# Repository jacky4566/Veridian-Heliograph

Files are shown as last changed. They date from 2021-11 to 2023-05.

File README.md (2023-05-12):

# Veridian-Heliograph
## What is it?
A hardy solar powered giver of GPS XYZ. Born from a need to always have a GPS device that can run for decades without any lithium batteries.
The Heliograph seeks to always provide a GPS Lat/Long position for the most severe travelers.
The whole device is cast in water clear epoxy, no ports, no holes, no batteries. Just a robust device that will provide a GPS position whenever outside.
A single M4 thread is provided for keychain or mounting on your favorite motorbike.

## Who wants it?
- Offshore Sailors
- Motorbikers
- Outdoorsmen
- Overlanders
- GNSS nerds

## Expected life
TBD

## Tech Features
- 2x 160mW solar panels
- TI nA Buck-Boost TPS63802
- 3.6V 70F Hybrid supercap
- UBlox Ultra low power M10 GPS processor
- STM32L432 MCU
- 3 Axis accelerometer with tap input, LIS3DH
- Sharp Sun readable Memory Display
- M4 screw thread for keychain or mounting

# Development and Details

## POWER SYSTEM
The power system comprises of 2 high efficiency solar panels at 120 degrees.  With this approach I hope the product design will always have access to some light to charge the super caps. Incoming power from the solar panels is feed through individual low drop shotcky diodes. With the diodes we loose ~200mV which is acceptable. 

The Supercaps are feed into Ti TPS63802 which provides buck-boost topography from the supercaps. Effectively allowing maximum use of the supercaps linear charge. 1.3 - 5.5V should be supported. Ti does also make an integrated BQ25570 MPPT with buck however I wanted to maximize the super caps voltage range.

VDD was selected at 3.0 volts as this was the minimum for the Sharp Memory LCD and the uBlox M10 GNSS chip. The M10 chip does also have a 1.8V version however we are still limited by the LCD. It might be possible to add a level converter however that quickly increases our BOM. The Buck-Boost seems like a good balance of low BOM and high efficiency.

## FIRMWARE
The firmware was written with the help of STM32CUBEIDE. The CubeIDE is pretty great for pre-generated code however some aspects can be hard to figure out for a novice. Since the BLE code could already be generated by the IDE most of my work was focused on the board level integration. Reading the sensors and putting that data into a nice GUI.
Firmware Features:
-	16MHz CPU speed coupled with 32.768kHz real time clock.
-	ADC 1Hz with DMA functionality to gather voltages. Supercap, temperature, and solar voltages.
-	SPI Display updating
-	GNSS processing using the Ublox PVT message. Less bytes to process compared to traditional NEMA messages. Super-e ultra low power tracking is set along side a software standby.
-	Accelerometer processing and Tap inputs

Some programming challenges I faced with my fight against CubeIDE:
-	Setting up the ADC DMA with proper callbacks. Some of the HAL calls need to be just right for the desired callbacks.
-	Learing about the SHARP display strange packet formatting. Data needs to be send as LSB.

## Housing
The Heliograph is essential without a housing. A basic model was 3D printed, then a reverse mold was made in rubber so the PCB and solar panels could be placed in a cavity and cast. Further development to come here.

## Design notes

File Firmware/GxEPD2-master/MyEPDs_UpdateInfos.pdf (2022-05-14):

List of my e-paper displays and their update times and behavior

size | | | panel | controller | full update | | | | comment
inches | depth | pixel | | | time sec | time sec | to buffer | to screen
1,54 | b/w | 200x200 | GDEP015OC1 | IL3829 | 1,2 | 0,3 | √ | √
1,54 | 3-color | 200x200 | GDEW0154Z04 | IL0376F | 7,2 | 7,2 | - | - | controller has no window part addressing
2,13 | b/w | 128x250 | GDE0213B1 | IL3895 | 3,9 | 0,3 | √ | √ | phased out
2,13 | b/w | 128x250 | GDEH0213B72 | IL3897 | 1,7 | 0,2 | √ | √ | new replacement
2,13 | b/w | 128x250 | GDEH0213B73 | SSD1675B | 3,8 | 0,2 | √ | √ | newer replacement
2,13 | 3-color | 104x212 | GDEW0213Z16 | IL0373 | 15 | 15 | √ | √ | screen boarder flashes also
2.13 | b/w | 104x212 | GDEW0213I5F | IL0373 | 2,1 | 0,3 | √ | √ | flexible display
2,6 | b/w | 152x296 | GDEW026T0 | IL0373 | 1,6 | 1,3 | √ | √
2,7 | b/w | 176x264 | GDEW027W3 | IL91874 | 2 | 0,4 | √ | √ | with wavetable from new demo source
2,7 | 3-color | 176x264 | GDEW027C44 | IL91874 | 16 | 16 | √ | √ | leaves visible boarder of partial window
2,9 | b/w | 128x296 | GDEH029A1 | IL3820 | 1,6 | 0,42 | √ | √
2,9 | b/w | 128x296 | GDEW029T5 | IL0373 | 2,1 | 0,4 | √ | √
2,9 | 3-color | 128x296 | GDEW029Z10 | IL0373 | 15 | 15 | √ | √ | screen boarder flashes also
3,7 | b/w | 240x416 | GDEW0371W7 | IL0324 | 3 | 1,5 | √ | √ | charge balancing waveform table for differential update
4,2 | b/w | 400x300 | GDEW042T2 | IL0398 | 1,6 | 0,6 | √ | √ | new waveform table for differential update
4,2 | 3-color | 400x300 | GDEW042Z15 | IL0398 | 16 | 16 | √ | - | refresh to partial screen would modify the other half screen
5,83 | b/w | 600x448 | GDEW0583T7 | IL0371 | 15 | 15 | √ | - | controller provides no differential update
7,5 | b/w | 640x384 | GDEW075T8 | IL0371 | 4,3 | 4,3 | √ | - | controller provides no differential update
7,5 | b/w | 800x480 | GDEW075T7 | GD7965 | 4,2 | 1,6 | √ | √ | charge balancing waveform table for differential update
7,5 | 3-color | 640x384 | GDEW075Z09 | IL0371 | 32 | 32 | √ | - | controller provides no differential update
7,5 | 3-color | 800x480 | GDEW075Z08 | GD7965 | 17 | 17 | √ | (√) | 3-color allows no differential update

times are "busy active" times after refresh command sent to controller
"-" partial update to screen: whole screen updates (and flashes)
(√) partial update can be disabled in GxEPD2 (usePartialUpdate = false) for better image

4.2" b/w: new waveform table for differential update, compromise between ghosting and persistence

resolution | partial update

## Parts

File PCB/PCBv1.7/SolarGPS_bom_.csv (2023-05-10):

Component | Description | Part | References | Value | Footprint | Quantity Per PCB | Datasheet | Manufacture | Category | DK_Datasheet_Link | DK_Detail_Page | Digi-Key_PN | Family | MPN | Manufacturer | Status
1 | Unpolarized capacitor, small symbol | C_Small | C13 C15 | 11pF | C_0603_1608Metric | 2 | ~
2 | Unpolarized capacitor, small symbol | C_Small | C1 C2 C3 C6 C7 C8 C12 C14 C16 C17 | 1uF | C_0603_1608Metric | 10 | ~
3 | Unpolarized capacitor, small symbol | C_Small | C9 C10 | 22uF | C_1206_3216Metric | 2 | ~
4 | Polarized capacitor | C_Polarized | C4 | 70F | TPLC3R8-25MR8X20 | 1 | ~
5 | Light emitting diode, small symbol | LED_Small | D1 | LED_Small | D_0805_2012Metric | 1 | ~
6 | Generic connector, single row, 01x04, script generated (kicad-library-utils/schlib/autogen/connector/) | Conn_01x04_Male | J8 | Conn_01x04_Male | PinSocket_1x04_P2.54mm_Vertical | 1 | ~
7 | Generic connector, single row, 01x10, script generated (kicad-library-utils/schlib/autogen/connector/) | Conn_01x10_Female | J1 | Conn_01x10_Female | LS013B7DH03 | 1 | ~
8 | Generic connector, double row, 02x03, odd/even pin numbering scheme (row 1 odd numbers, row 2 even numbers), script generated (kicad-library-utils/schlib/autogen/connector/) | Conn_02x03_Odd_Even | J6 | Conn_02x03_Odd_Even | Tag-Connect_TC2030-IDC-NL_2x03_P1.27mm_Vertical | 1 | ~
9 | Generic connector, single row, 01x01, script generated (kicad-library-utils/schlib/autogen/connector/) | Conn_01x01_Female | J2 J3 J4 J5 | GND | PinHeader_1x01_P2.54mm_Vertical | 4 | ~
10 | Generic screw terminal, single row, 01x01, script generated (kicad-library-utils/schlib/autogen/connector/) | Screw_Terminal_01x01 | J7 | Screw_Terminal_01x01 | M4_RA_7792 | 1 | ~ | Keystone Electronics
11 | USB 2.0-only Type-C Receptacle connector | USB_C_Receptacle_USB2.0 | J9 | USB_C_Receptacle_USB2.0 | USB_TYPE_C_PCB | 1 | https://www.usb.org/sites/default/files/documents/usb_type-c.zip
12 | Inductor, small symbol | L_Small | L1 | 0.47uH | L_0805_2012Metric_Pad1.15x1.40mm_HandSolder | 1 | ~
13 | Resistor, small symbol | R_Small | R10 | 10 | R_0805_2012Metric | 1 | ~
14 | Resistor, small symbol | R_Small | R8 R9 R11 R13 | 5.1K | R_0603_1608Metric | 4 | ~
15 | Resistor, small symbol | R_Small | R1 R4 R7 R12 | 86.6k | R_0603_1608Metric | 4 | ~
16 | Resistor, small symbol | R_Small | R2 R3 R6 | 432k | R_0603_1608Metric | 3 | ~
17 | IMU ACCEL/GYRO I2C/SPI 14LGA | BMI160 | U4 | BMI160 | BMI160 | 1 | https://ae-bst.resource.bosch.com/media/_tech/media/datasheets/BST-BMI160-DS000.pdf |  | Sensors, Transducers | https://ae-bst.resource.bosch.com/media/_tech/media/datasheets/BST-BMI160-DS000.pdf | /product-detail/en/bosch-sensortec/BMI160/828-1057-1-ND/6136308 | 828-1057-1-ND | Motion Sensors - IMUs (Inertial Measurement Units) | BMI160 | Bosch Sensortec | Active
18 | Ideal Diode, Ultra-Low Voltage Drop, 1.5-5.5V, 1A, SOT-23-5 | MAX40200AUK | U5 U6 U7 | MAX40200AUK | SOT-23-5 | 3 | https://datasheets.maximintegrated.com/en/ds/MAX40200.pdf
19 | GPS ublox M8 variant | SAM-M8Q | U2 | SAM-M10Q | ublox_SAM-M8Q | 1 | https://www.u-blox.com/sites/default/files/SAM-M8Q_DataSheet_%28UBX-16012619%29.pdf
20 | ARM Cortex-M4 MCU, 256KB flash, 64KB RAM, 80MHz, 1.71-3.6V, 26 GPIO, UFQFPN-32 | STM32L432KCUx | U3 | STM32L432KCUx | QFN-32-1EP_5x5mm_P0.5mm_EP3.45x3.45mm | 1 | http://www.st.com/st-web-ui/static/active/en/resource/technical/document/datasheet/DM00257205.pdf
21 |  | TPS63802-VeridianDesigns | U1 | TPS63802 | VREG_TPS63802DLAR | 1
22 | Very low capacitance ESD protection diode, 2 data-line, SOT-23-6 | USBLC6-2SC6 | U8 | USBLC6-2SC6 | SOT-23-6 | 1 | https://www.st.com/resource/en/datasheet/usblc6-2.pdf
23 | Two pin crystal | Crystal | Y1 | 32.768 | Crystal_SMD_3215-2Pin_3.2x1.5mm | 1 | ~
Component Groups: | 23
Component Count: | 47
Fitted Components: | 47
Number of PCBs: | 1
Total components: | 47
Schematic Version:
Schematic Date:
PCB Variant: | default
BoM Date: | 27-Apr-23 3:35:01 PM
Schematic Source: | SolarGPS.kicad_sch
KiCad Version: | Eeschema (6.0.10)

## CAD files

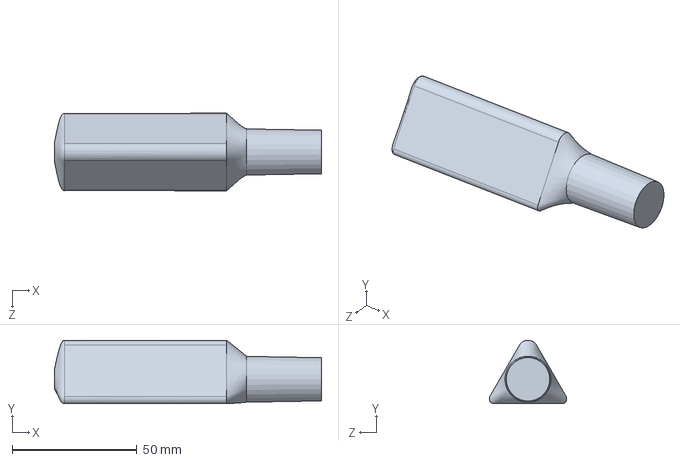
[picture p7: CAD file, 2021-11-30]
3D Models/Model1.SLDPRT
107.0 x 25.4 x 31.1 mm

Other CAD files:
3D Models/Model1.STL

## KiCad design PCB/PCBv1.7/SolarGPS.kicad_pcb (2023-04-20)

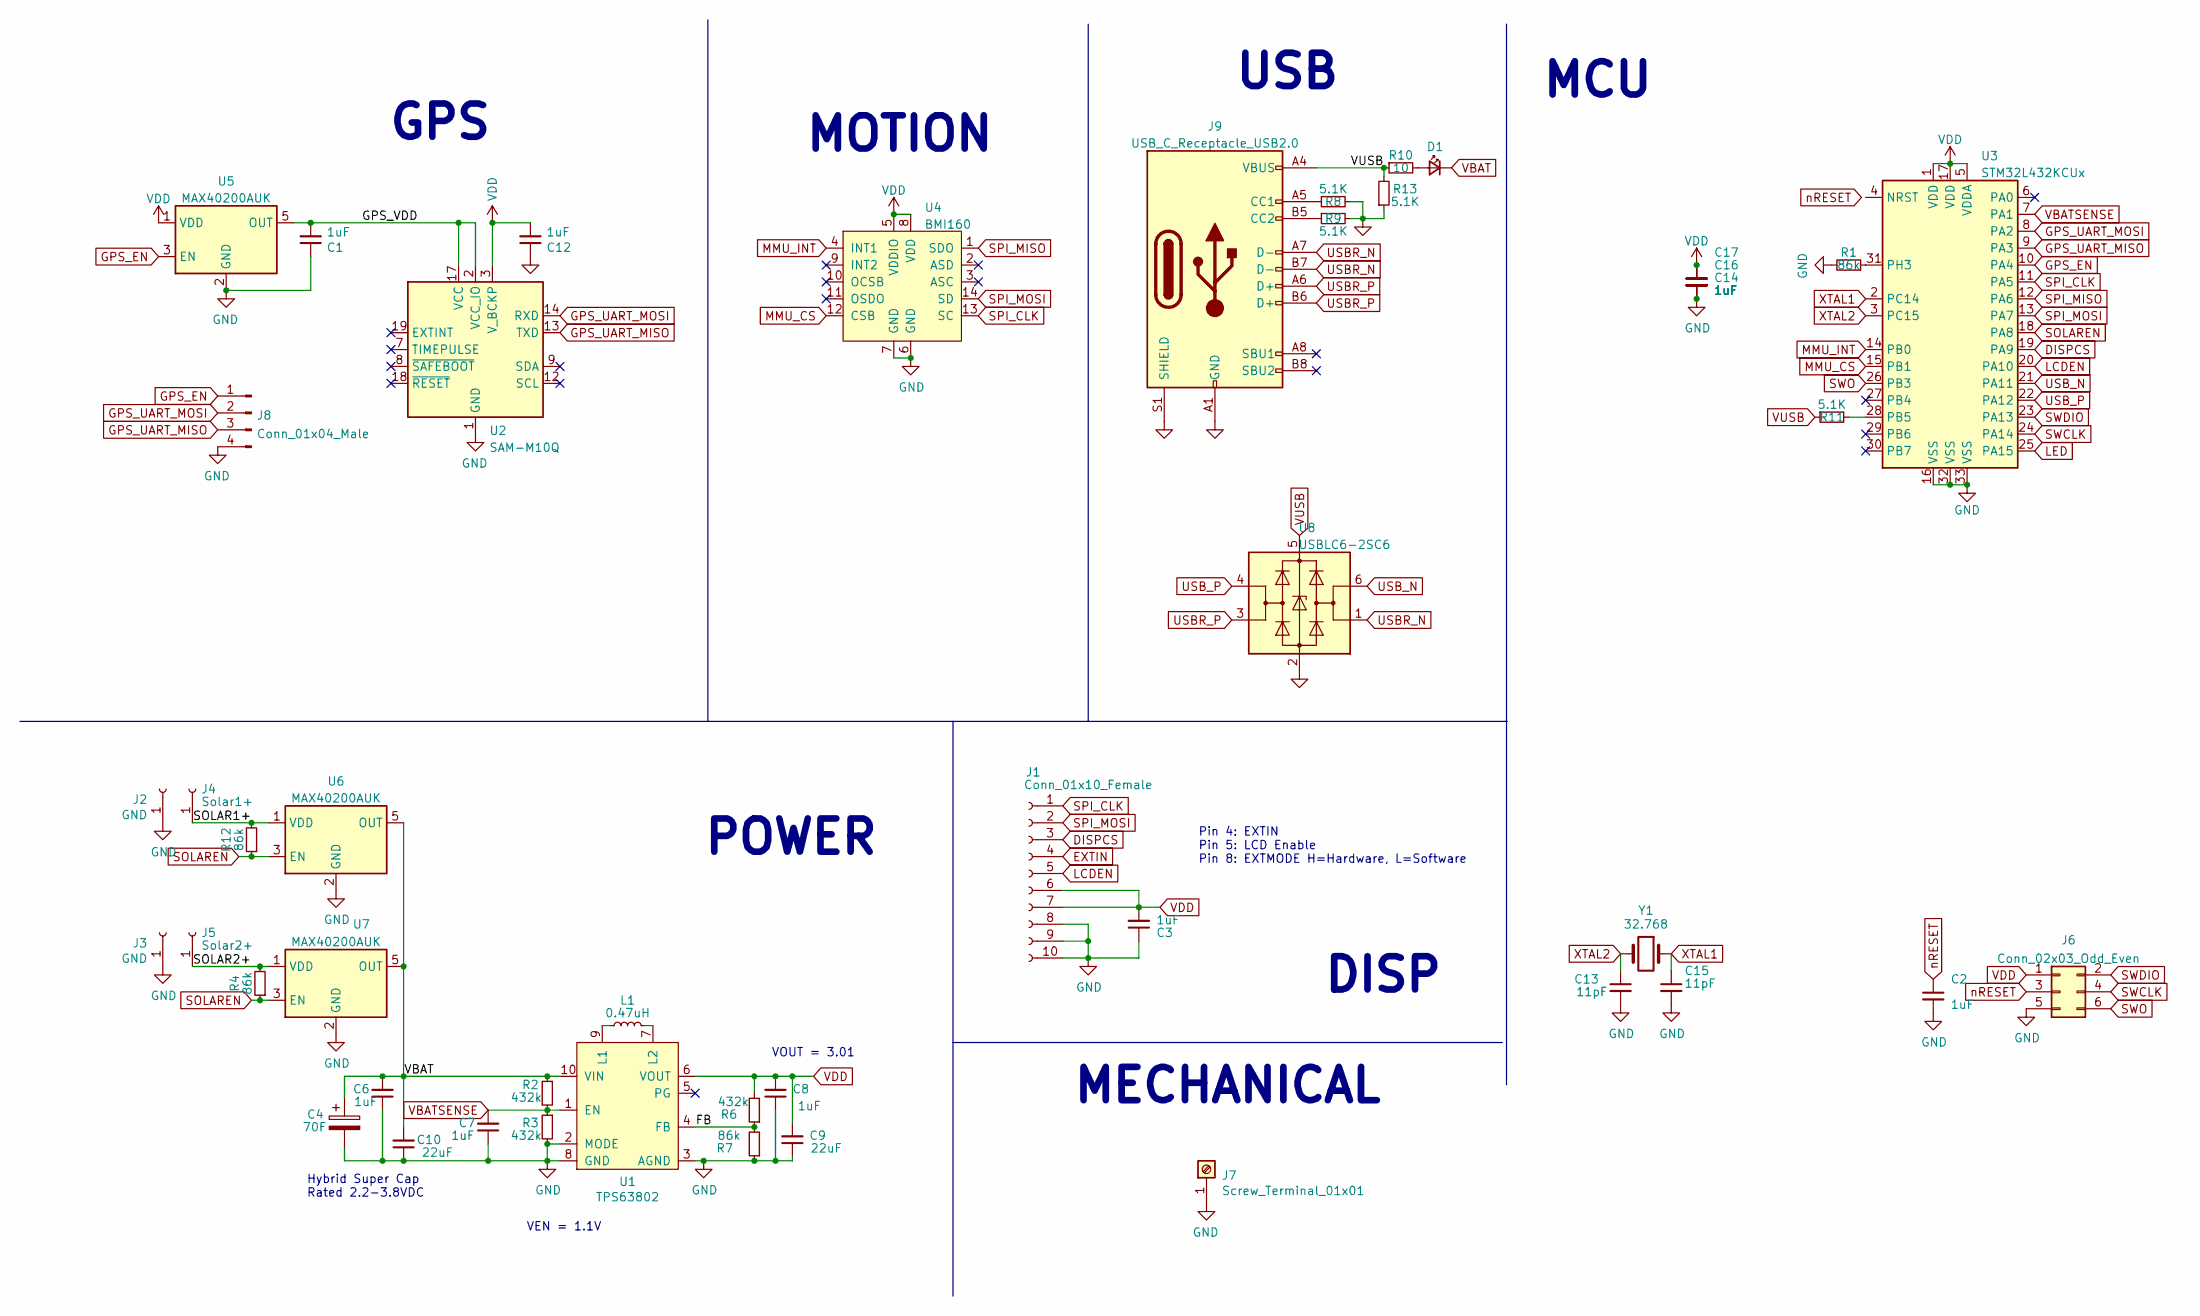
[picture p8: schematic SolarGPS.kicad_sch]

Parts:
C1, C2, C3, C6, C7, C8, C12, C14, C16, C17: 1uF; C_0603_1608Metric
C4: 70F; TPLC3R8-25MR8X20; Part TPLC3R8-25MR8X20
C9, C10: 22uF; C_1206_3216Metric
C13, C15: 11pF; C_0603_1608Metric
D1: LED_Small; D_0805_2012Metric
J1: Conn_01x10_Female; LS013B7DH03
J2, J3: GND; PinHeader_1x01_P2.54mm_Vertical
J4: Solar1+; PinHeader_1x01_P2.54mm_Vertical
J5: Solar2+; PinHeader_1x01_P2.54mm_Vertical
J6: Conn_02x03_Odd_Even; Tag-Connect_TC2030-IDC-NL_2x03_P1.27mm_Vertical
J7: Screw_Terminal_01x01; M4_RA_7792; Part 7792
J8: Conn_01x04_Male; PinSocket_1x04_P2.54mm_Vertical
J9: USB_C_Receptacle_USB2.0; USB_TYPE_C_PCB
L1: 0.47uH; L_0805_2012Metric_Pad1.15x1.40mm_HandSolder; Part DFE201612E
R1, R4, R7, R12: 86k; R_0603_1608Metric
R2, R3, R6: 432k; R_0603_1608Metric
R8, R9, R11, R13: 5.1K; R_0603_1608Metric
R10: 10; R_0805_2012Metric
U1: TPS63802; VREG_TPS63802DLAR
U2: SAM-M10Q; ublox_SAM-M8Q
U3: STM32L432KCUx; QFN-32-1EP_5x5mm_P0.5mm_EP3.45x3.45mm
U4: BMI160; MPN BMI160; Digi-Key_PN 828-1057-1-ND
U5, U6, U7: MAX40200AUK; SOT-23-5
U8: USBLC6-2SC6; SOT-23-6
Y1: 32.768; Crystal_SMD_3215-2Pin_3.2x1.5mm; Part SC32S-7PF20PPM

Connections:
/FB: R6.1, R7.2, U1.4 (FB)
/GPS_VDD: C1.2, U2.2 (VCC_IO), U2.17 (VCC), U5.5 (OUT)
/SOLAR1+: J4.1, R12.2, U6.1 (VDD)
/SOLAR2+: J5.1, R4.2, U7.1 (VDD)
DISPCS: J1.3, U3.19 (PA9)
EXTIN: J1.4
GND: C1.1, C2.2, C3.1, C4.2, C6.1, C7.1, C8.1, C9.1, C10.1, C12.1, C13.2, C14.2, C15.2, C16.2, C17.2, J1.8, J1.9, J1.10, J2.1, J3.1, J6.5, J7.1, J8.4, J9.A1 (GND), J9.A12 (GND), J9.B1 (GND), J9.B12 (GND), J9.S1 (SHIELD), R1.2, R3.2, R7.1, R8.2, R9.2, R13.1, U1.2 (MODE), U1.3 (AGND), U1.8 (GND), U2.1 (GND), U2.4 (GND), U2.5 (GND), U2.6 (GND), U2.10 (GND), U2.11 (GND), U2.15 (GND), U2.16 (GND), U2.20 (GND), U3.16 (VSS), U3.32 (VSS), U3.33 (VSS), U4.6 (GND), U4.7 (GND), U5.2 (GND), U6.2 (GND), U7.2 (GND), U8.2 (GND)
GPS_EN: J8.1, U3.10 (PA4), U5.3 (EN)
GPS_UART_MISO: J8.3, U2.13 (TXD), U3.9 (PA3)
GPS_UART_MOSI: J8.2, U2.14 (RXD), U3.8 (PA2)
LCDEN: J1.5, U3.20 (PA10)
LED: U3.25 (PA15)
MMU_CS: U3.15 (PB1), U4.12 (CSB)
MMU_INT: U3.14 (PB0), U4.4 (INT1)
unnamed: D1.2 (A), R10.2
unnamed: J9.A5 (CC1), R8.1
unnamed: J9.B5 (CC2), R9.1
unnamed: L1.1, U1.9 (L1)
unnamed: L1.2, U1.7 (L2)
unnamed: R1.1, U3.31 (PH3)
unnamed: R11.2, U3.28 (PB5)
SOLAREN: R4.1, R12.1, U3.18 (PA8), U6.3 (EN), U7.3 (EN)
SPI_CLK: J1.1, U3.11 (PA5), U4.13 (SC)
SPI_MISO: U3.12 (PA6), U4.1 (SDO)
SPI_MOSI: J1.2, U3.13 (PA7), U4.14 (SD)
SWCLK: J6.4, U3.24 (PA14)
SWDIO: J6.2, U3.23 (PA13)
SWO: J6.6, U3.26 (PB3)
USBR_N: J9.A7 (D-), J9.B7 (D-), U8.1 (I/O1)
USBR_P: J9.A6 (D+), J9.B6 (D+), U8.3 (I/O2)
USB_N: U3.21 (PA11), U8.6 (I/O1)
USB_P: U3.22 (PA12), U8.4 (I/O2)
VBAT: C4.1, C6.2, C10.2, D1.1 (K), R2.1, U1.10 (VIN), U6.5 (OUT), U7.5 (OUT)
VBATSENSE: C7.2, R2.2, R3.1, U1.1 (EN), U3.7 (PA1)
VDD: C3.2, C8.2, C9.2, C12.2, C14.1, C16.1, C17.1, J1.6, J1.7, J6.1, R6.2, U1.6 (VOUT), U2.3 (V_BCKP), U3.1 (VDD), U3.5 (VDDA), U3.17 (VDD), U4.5 (VDDIO), U4.8 (VDD), U5.1 (VDD)
VUSB: J9.A4 (VBUS), J9.A9 (VBUS), J9.B4 (VBUS), J9.B9 (VBUS), R10.1, R11.1, R13.2, U8.5 (VBUS)
XTAL1: C15.1, U3.2 (PC14), Y1.1
XTAL2: C13.1, U3.3 (PC15), Y1.2
nRESET: C2.1, J6.3

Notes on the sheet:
GPS
USB
MCU
Pin 4: EXTIN Pin 5: LCD Enable Pin 8: EXTMODE H=Hardware, L=Software
DISP
Hybrid Super Cap Rated 2.2-3.8VDC
VEN = 1.1V
POWER
VOUT = 3.01
MECHANICAL
MOTION

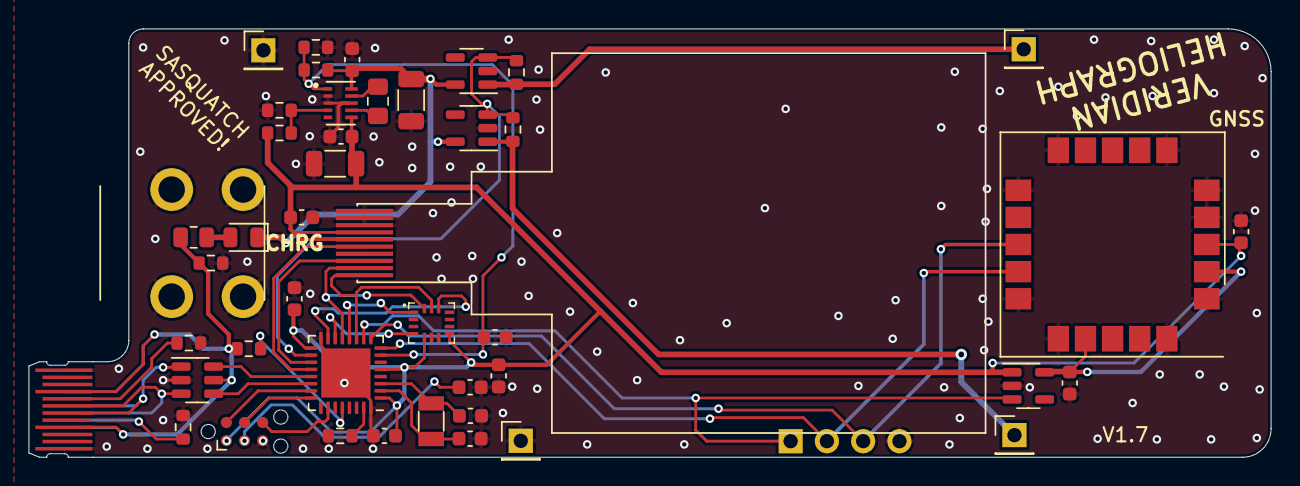
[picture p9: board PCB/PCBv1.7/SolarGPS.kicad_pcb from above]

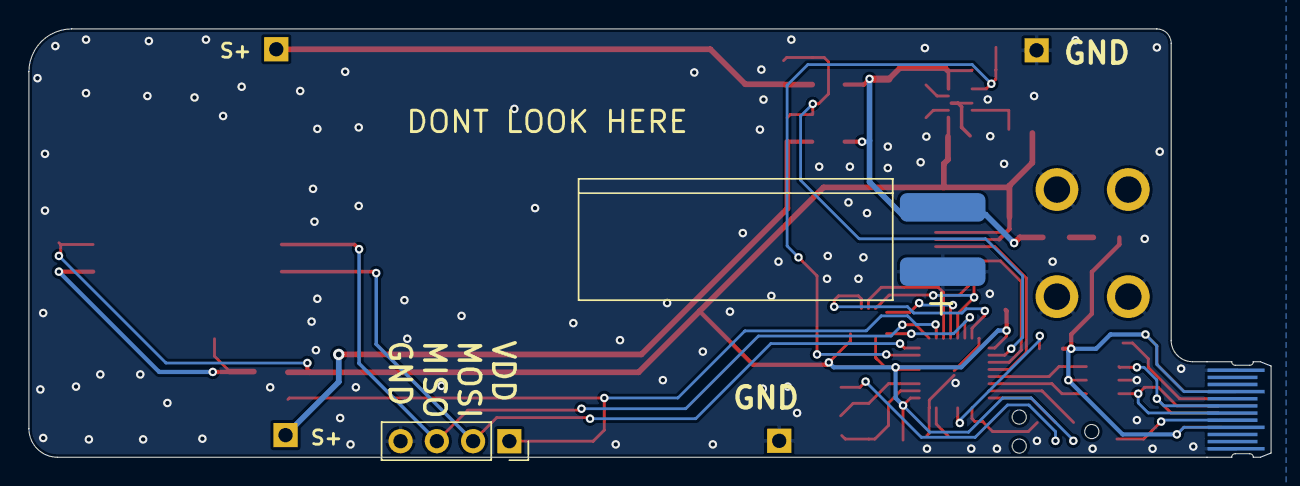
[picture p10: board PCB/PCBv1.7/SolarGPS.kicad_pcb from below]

Board: 2 copper layers, 87.0 x 30.0 mm, 47 parts (2 on the bottom side), 37 nets.

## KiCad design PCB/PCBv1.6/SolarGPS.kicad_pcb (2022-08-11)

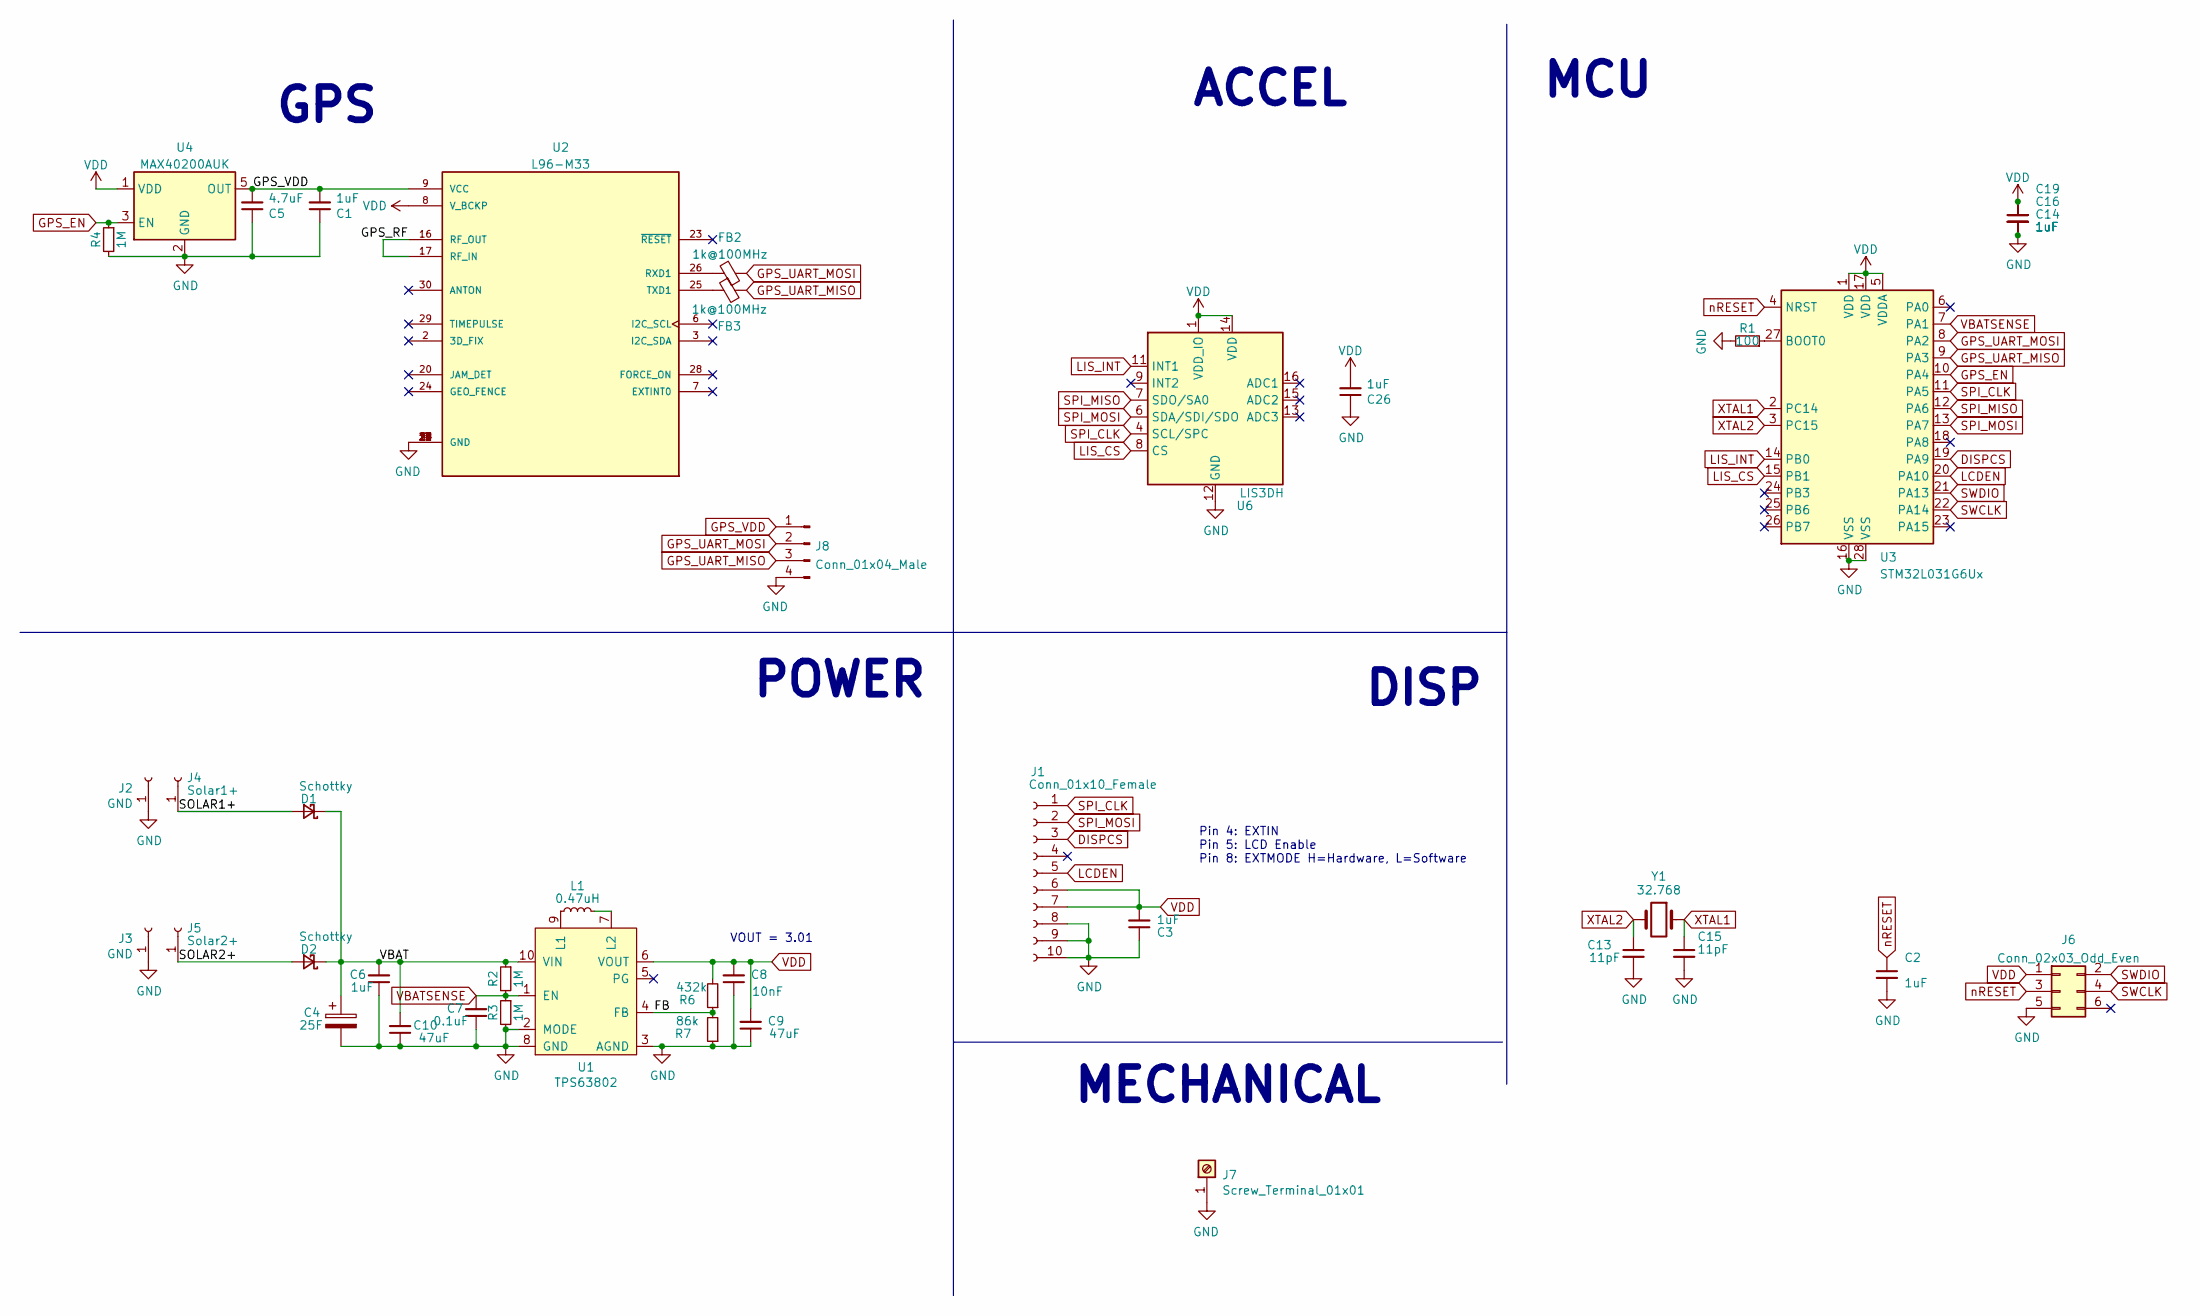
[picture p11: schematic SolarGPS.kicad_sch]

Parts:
C1, C2, C3, C6, C14, C16, C19, C26: 1uF; C_0603_1608Metric
C4: 25F; TPLC3R8-25MR8X20; Part TPLC3R8-25MR8X20
C5: 4.7uF; C_0805_2012Metric
C7: 0.1uF; C_0603_1608Metric
C8: 10nF; C_0603_1608Metric
C9, C10: 47uF; C_1206_3216Metric
C13, C15: 11pF; C_0603_1608Metric
D1, D2: Schottky; D_SOD-323_HandSoldering; Part B0530WS
FB2, FB3: 1k@100MHz; R_0603_1608Metric
J1: Conn_01x10_Female; LS013B7DH03
J2, J3: GND; PinHeader_1x01_P2.54mm_Vertical
J4: Solar1+; PinHeader_1x01_P2.54mm_Vertical
J5: Solar2+; PinHeader_1x01_P2.54mm_Vertical
J6: Conn_02x03_Odd_Even; Tag-Connect_TC2030-IDC-NL_2x03_P1.27mm_Vertical
J7: Screw_Terminal_01x01; M4_RA_7792; Part 7792
J8: Conn_01x04_Male; PinSocket_1x04_P2.54mm_Vertical
L1: 0.47uH; L_0805_2012Metric_Pad1.05x1.20mm_HandSolder; Part DFE201612E
R1: 100; R_0603_1608Metric
R2, R3, R4: 1M; R_0603_1608Metric
R6: 432k; R_0603_1608Metric
R7: 86k; R_0603_1608Metric
U1: TPS63802; VREG_TPS63802DLAR
U2: L96-M33; XCVR_L96-M33
U3: STM32L031G6Ux; QFN-28_4x4mm_P0.5mm
U4: MAX40200AUK; SOT-23-5
U6: LIS3DH; LGA-16_3x3mm_P0.5mm_LayoutBorder3x5y
Y1: 32.768; Crystal_SMD_3215-2Pin_3.2x1.5mm; Part SC32S-7PF20PPM

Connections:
/FB: R6.1, R7.2, U1.4 (FB)
/GPS_RF: U2.16 (RF_OUT), U2.17 (RF_IN)
/SOLAR1+: D1.2 (A), J4.1
/SOLAR2+: D2.2 (A), J5.1
/VBAT: C4.1, C6.2, C10.2, D1.1 (K), D2.1 (K), R2.1, U1.10 (VIN)
DISPCS: J1.3, U3.19 (PA9)
GND: C1.1, C2.2, C3.1, C4.2, C5.1, C6.1, C7.1, C8.1, C9.1, C10.1, C13.2, C14.2, C15.2, C16.2, C19.2, C26.1, J1.8, J1.9, J1.10, J2.1, J3.1, J6.5, J7.1, J8.4, R1.2, R3.2, R4.2, R7.1, U1.2 (MODE), U1.3 (AGND), U1.8 (GND), U2.4 (GND), U2.5 (GND), U2.10 (GND), U2.11 (GND), U2.12 (GND), U2.13 (GND), U2.14 (GND), U2.15 (GND), U2.18 (GND), U2.19 (GND), U2.21 (GND), U2.22 (GND), U2.27 (GND), U2.31 (GND), U3.16 (VSS), U3.28 (VSS), U4.2 (GND), U6.5 (GND), U6.10 (GND), U6.12 (GND)
GPS_EN: R4.1, U3.10 (PA4), U4.3 (EN)
GPS_UART_MISO: FB3.2, J8.3, U3.9 (PA3)
GPS_UART_MOSI: FB2.1, J8.2, U3.8 (PA2)
GPS_VDD: C1.2, C5.2, J8.1, U2.9 (VCC), U4.5 (OUT)
LCDEN: J1.5, U3.20 (PA10)
LIS_CS: U3.15 (PB1), U6.8 (CS)
LIS_INT: U3.14 (PB0), U6.11 (INT1)
unnamed: FB2.2, U2.26 (RXD1)
unnamed: FB3.1, U2.25 (TXD1)
unnamed: L1.1, U1.9 (L1)
unnamed: L1.2, U1.7 (L2)
unnamed: R1.1, U3.27 (BOOT0)
SPI_CLK: J1.1, U3.11 (PA5), U6.4 (SCL/SPC)
SPI_MISO: U3.12 (PA6), U6.7 (SDO/SA0)
SPI_MOSI: J1.2, U3.13 (PA7), U6.6 (SDA/SDI/SDO)
SWCLK: J6.4, U3.22 (PA14)
SWDIO: J6.2, U3.21 (PA13)
VBATSENSE: C7.2, R2.2, R3.1, U1.1 (EN), U3.7 (PA1)
VDD: C3.2, C8.2, C9.2, C14.1, C16.1, C19.1, C26.2, J1.6, J1.7, J6.1, R6.2, U1.6 (VOUT), U2.8 (V_BCKP), U3.1 (VDD), U3.5 (VDDA), U3.17 (VDD), U4.1 (VDD), U6.1 (VDD_IO), U6.14 (VDD)
XTAL1: C15.1, U3.2 (PC14), Y1.1
XTAL2: C13.1, U3.3 (PC15), Y1.2
nRESET: C2.1, J6.3, U3.4 (NRST)

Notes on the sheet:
GPS
MCU
ACCEL
Pin 4: EXTIN Pin 5: LCD Enable Pin 8: EXTMODE H=Hardware, L=Software
DISP
POWER
VOUT = 3.01
MECHANICAL

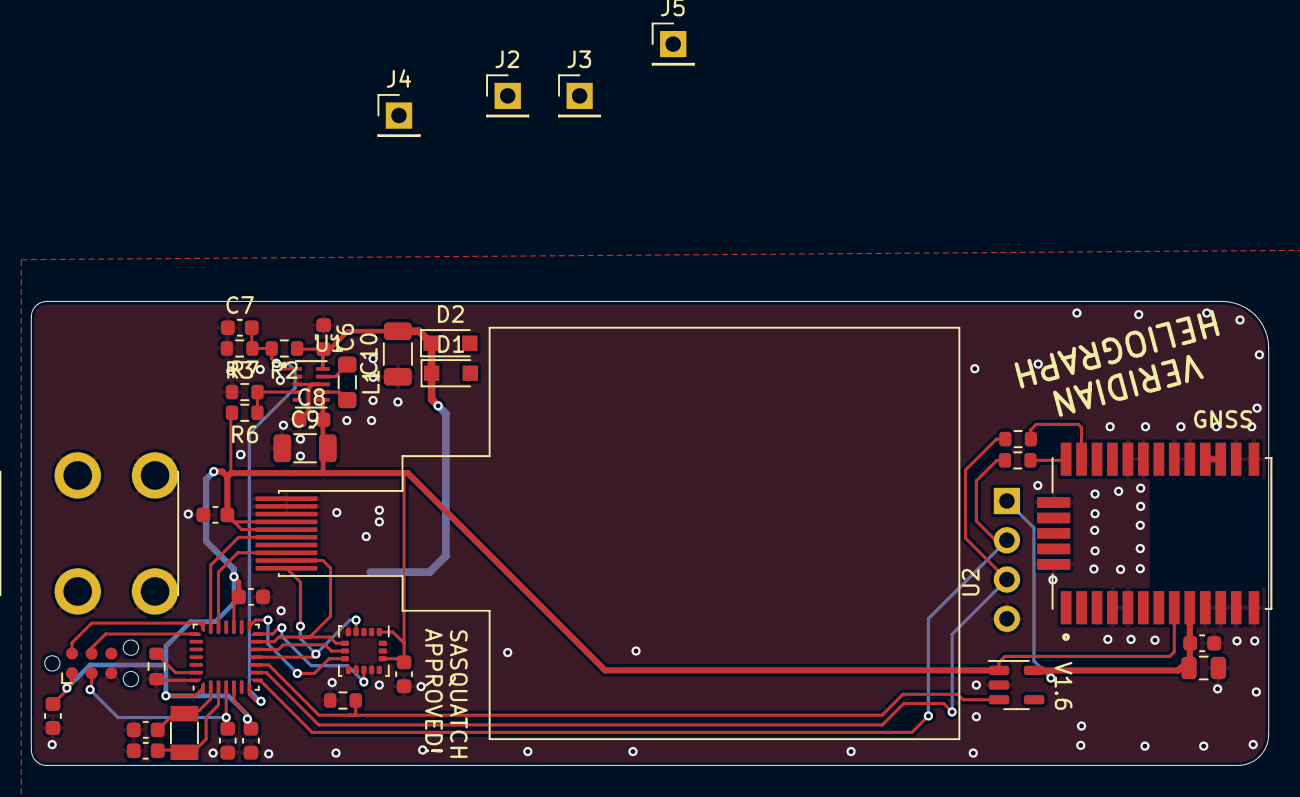
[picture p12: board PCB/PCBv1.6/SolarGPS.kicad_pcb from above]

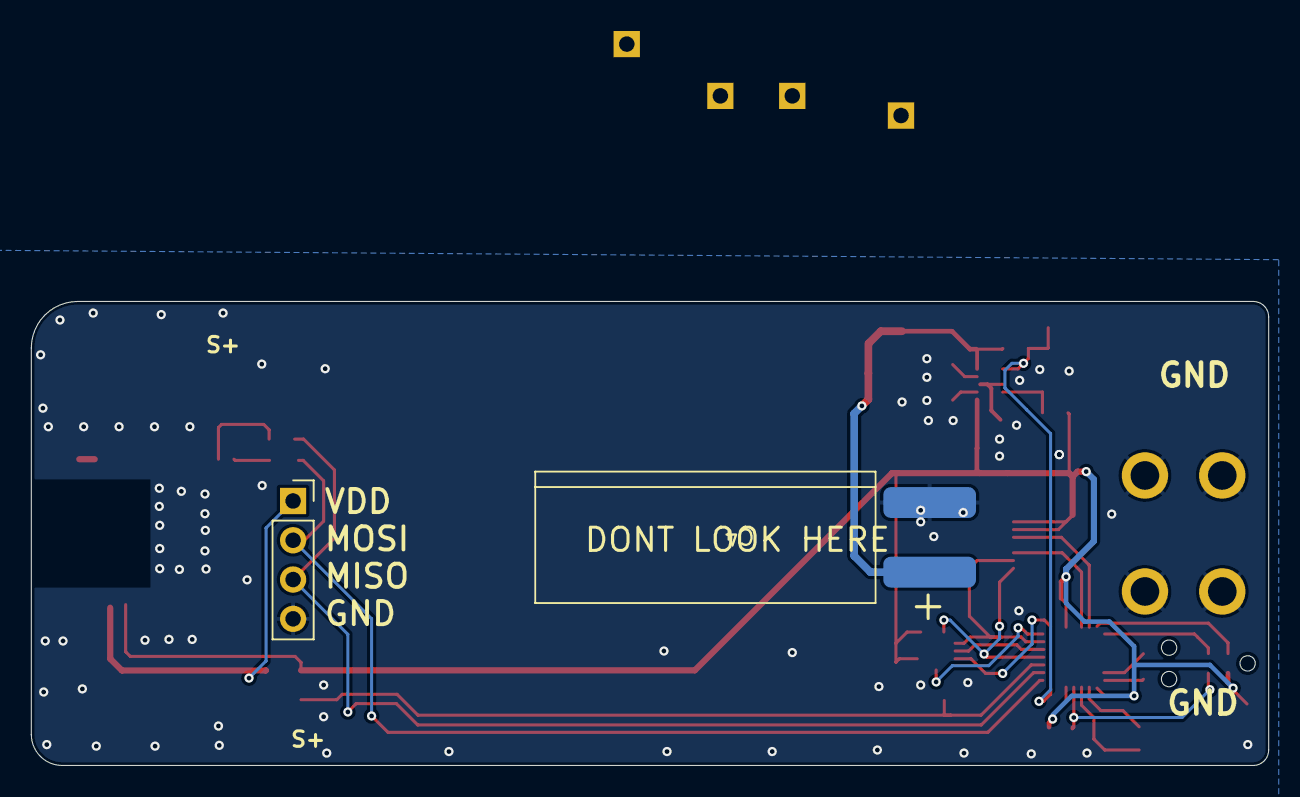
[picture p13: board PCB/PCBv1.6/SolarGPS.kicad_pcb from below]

Board: 2 copper layers, 80.0 x 30.0 mm, 41 parts (2 on the bottom side), 29 nets.

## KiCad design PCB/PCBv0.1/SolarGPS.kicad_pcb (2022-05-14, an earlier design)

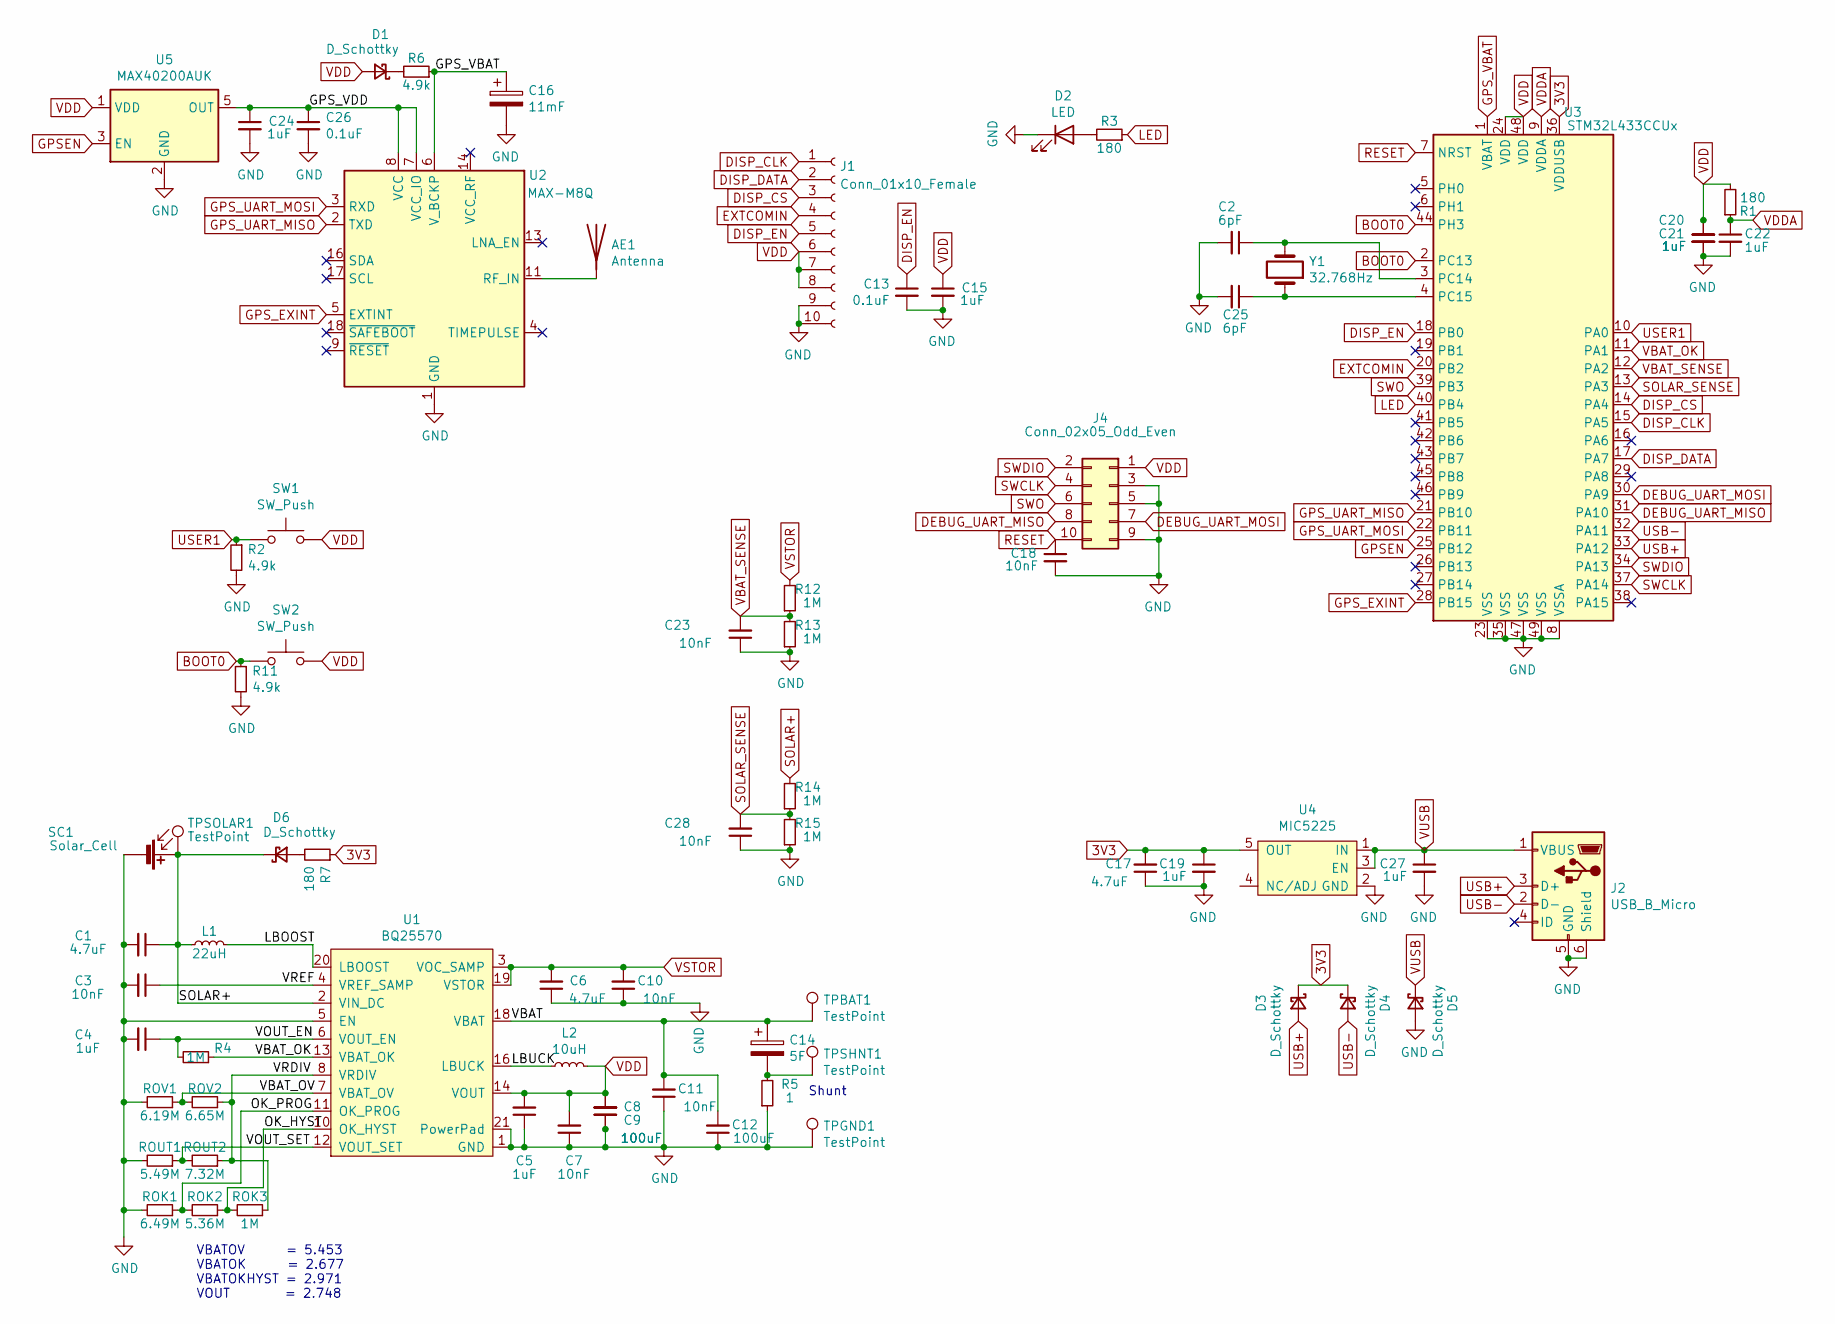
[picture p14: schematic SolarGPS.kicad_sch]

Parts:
AE1: Antenna; CGIP.25.4.A.02
C1, C6, C17: 4.7uF; C_0805_2012Metric
C2, C25: 6pF; C_0603_1608Metric
C3, C7, C10, C11, C18, C23, C28: 10nF; C_0603_1608Metric
C4, C5, C15, C19, C20, C21, C22, C24, C27: 1uF; C_0603_1608Metric
C8, C9, C12: 100uF; C_1206_3216Metric
C13, C26: 0.1uF; C_0603_1608Metric
C14: 5F; PinHeader_1x02_P2.54mm_Vertical
C16: 11mF; C_1210_3225Metric; Part CPH3225A
D1, D3, D4, D5, D6: D_Schottky; D_SOD-523
D2: LED; D_0805_2012Metric; PArt LTST-S270CKT
J1: Conn_01x10_Female; AYF531035
J2: USB_B_Micro; USB_Micro-B_GCT_USB3076-30-A
J4: Conn_02x05_Odd_Even; PinHeader_2x05_P2.00mm_Vertical_SMD
L1: 22uH; 744031220; Part 744031220
L2: 10uH; 744029100; Part 744029100
R1, R3, R7: 180; R_0603_1608Metric
R2, R6, R11: 4.9k; R_0603_1608Metric
R4, R12, R13, R14, R15: 1M; R_0603_1608Metric
R5: 1; R_0603_1608Metric
ROK1: 6.49M; R_0603_1608Metric
ROK2: 5.36M; R_0603_1608Metric
ROK3: 1M; R_0603_1608Metric
ROUT1: 5.49M; R_0603_1608Metric
ROUT2: 7.32M; R_0603_1608Metric
ROV1: 6.19M; R_0603_1608Metric
ROV2: 6.65M; R_0603_1608Metric
SC1: Solar_Cell; SM141K09L
SW1, SW2: SW_Push; SW_Push_1P1T_NO_6x6mm_H9.5mm; Part KSC471G 70SH LFS PF
TPBAT1: TestPoint; TestPoint_THTPad_1.0x1.0mm_Drill0.5mm
TPGND1: TestPoint; TestPoint_THTPad_1.0x1.0mm_Drill0.5mm
TPSHNT1: TestPoint; TestPoint_THTPad_1.0x1.0mm_Drill0.5mm
TPSOLAR1: TestPoint; TestPoint_THTPad_1.0x1.0mm_Drill0.5mm
U1: BQ25570; QFN-20-1EP_3.5x3.5mm_P0.5mm_EP2x2mm
U2: MAX-M8Q; ublox_MAX
U3: STM32L433CCUx; QFN-48-1EP_7x7mm_P0.5mm_EP5.6x5.6mm
U4: MIC5225; SOT-23-5
U5: MAX40200AUK; SOT-23-5
Y1: 32.768Hz; Crystal_SMD_3215-2Pin_3.2x1.5mm; Part CM315D

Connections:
3V3: C17.2, C19.1, D3.1 (K), D4.1 (K), R7.1, U3.36 (VDDUSB), U4.5 (OUT)
/GPS_VDD: C24.1, C26.1, U2.7 (VCC_IO), U2.8 (VCC), U5.5 (OUT)
/LBOOST: L1.2, U1.20 (LBOOST)
/LBUCK: L2.1, U1.16 (LBUCK)
/OK_HYST: ROK2.1, ROK3.2, U1.10 (OK_HYST)
/OK_PROG: ROK1.1, ROK2.2, U1.11 (OK_PROG)
/VBAT: C11.2, C12.2, C14.1, TPBAT1.1, U1.18 (VBAT)
/VBAT_OV: ROV1.1, ROV2.2, U1.7 (VBAT_OV)
/VOUT_EN: C4.1, R4.2, U1.6 (VOUT_EN)
/VOUT_SET: ROUT1.1, ROUT2.2, U1.12 (VOUT_SET)
/VRDIV: ROK3.1, ROUT2.1, ROV2.1, U1.8 (VRDIV)
/VREF: C3.1, U1.4 (VREF_SAMP)
BOOT0: R11.1, SW2.1, U3.2 (PC13), U3.44 (PH3)
DEBUG_UART_MISO: J4.8, U3.31 (PA10)
DEBUG_UART_MOSI: J4.7, U3.30 (PA9)
DISP_CLK: J1.1, U3.15 (PA5)
DISP_CS: J1.3, U3.14 (PA4)
DISP_DATA: J1.2, U3.17 (PA7)
DISP_EN: C13.1, J1.5, U3.18 (PB0)
EXTCOMIN: J1.4, U3.20 (PB2)
GND: C1.2, C2.2, C3.2, C4.2, C5.1, C6.1, C7.1, C8.1, C9.1, C10.1, C11.1, C12.1, C13.2, C15.2, C16.2, C17.1, C18.2, C19.2, C20.2, C21.2, C22.2, C23.1, C24.2, C25.2, C26.2, C27.2, C28.1, D2.1 (K), D5.2 (A), J1.9, J1.10, J2.5 (GND), J2.6 (Shield), J4.3, J4.5, J4.9, R2.2, R5.1, R11.2, R13.1, R15.1, ROK1.2, ROUT1.2, ROV1.2, SC1.2 (-), TPGND1.1, U1.1 (GND), U1.5 (EN), U1.9 (GND), U1.15 (GND), U1.17 (GND), U1.21 (PowerPad), U2.1 (GND), U2.10 (GND), U2.12 (GND), U3.8 (VSSA), U3.23 (VSS), U3.35 (VSS), U3.47 (VSS), U3.49 (VSS), U4.2 (GND), U5.2 (GND)
GPSEN: U3.25 (PB12), U5.3 (EN)
GPS_EXINT: U2.5 (EXTINT), U3.28 (PB15)
GPS_UART_MISO: U2.2 (TXD), U3.21 (PB10)
GPS_UART_MOSI: U2.3 (RXD), U3.22 (PB11)
GPS_VBAT: C16.1, R6.1, U2.6 (V_BCKP), U3.1 (VBAT)
LED: R3.1, U3.40 (PB4)
unnamed: AE1.1 (A), U2.11 (RF_IN)
unnamed: C2.1, U3.3 (PC14), Y1.2
unnamed: C14.2, R5.2, TPSHNT1.1
unnamed: C25.1, U3.4 (PC15), Y1.1
unnamed: D1.1 (K), R6.2
unnamed: D2.2 (A), R3.2
unnamed: D6.2 (A), R7.2
RESET: C18.1, J4.10, U3.7 (NRST)
SOLAR+: C1.1, D6.1 (K), L1.1, R14.2, SC1.1 (+), TPSOLAR1.1, U1.2 (VIN_DC)
SOLAR_SENSE: C28.2, R14.1, R15.2, U3.13 (PA3)
SWCLK: J4.4, U3.37 (PA14)
SWDIO: J4.2, U3.34 (PA13)
SWO: J4.6, U3.39 (PB3)
USB+: D3.2 (A), J2.3 (D+), U3.33 (PA12)
USB-: D4.2 (A), J2.2 (D-), U3.32 (PA11)
USER1: R2.1, SW1.1, U3.10 (PA0)
VBAT_OK: R4.1, U1.13 (VBAT_OK), U3.11 (PA1)
VBAT_SENSE: C23.2, R12.1, R13.2, U3.12 (PA2)
VDD: C5.2, C7.2, C8.2, C9.2, C15.1, C20.1, C21.1, D1.2 (A), J1.6, J1.7, J1.8, J4.1, L2.2, R1.2, SW1.2, SW2.2, U1.14 (VOUT), U3.24 (VDD), U3.48 (VDD), U5.1 (VDD)
VDDA: C22.1, R1.1, U3.9 (VDDA)
VSTOR: C6.2, C10.2, R12.2, U1.3 (VOC_SAMP), U1.19 (VSTOR)
VUSB: C27.1, D5.1 (K), J2.1 (VBUS), U4.1 (IN), U4.3 (EN)

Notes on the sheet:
VBATOV = 5.453 VBATOK = 2.677 VBATOKHYST = 2.971 VOUT = 2.748
Shunt

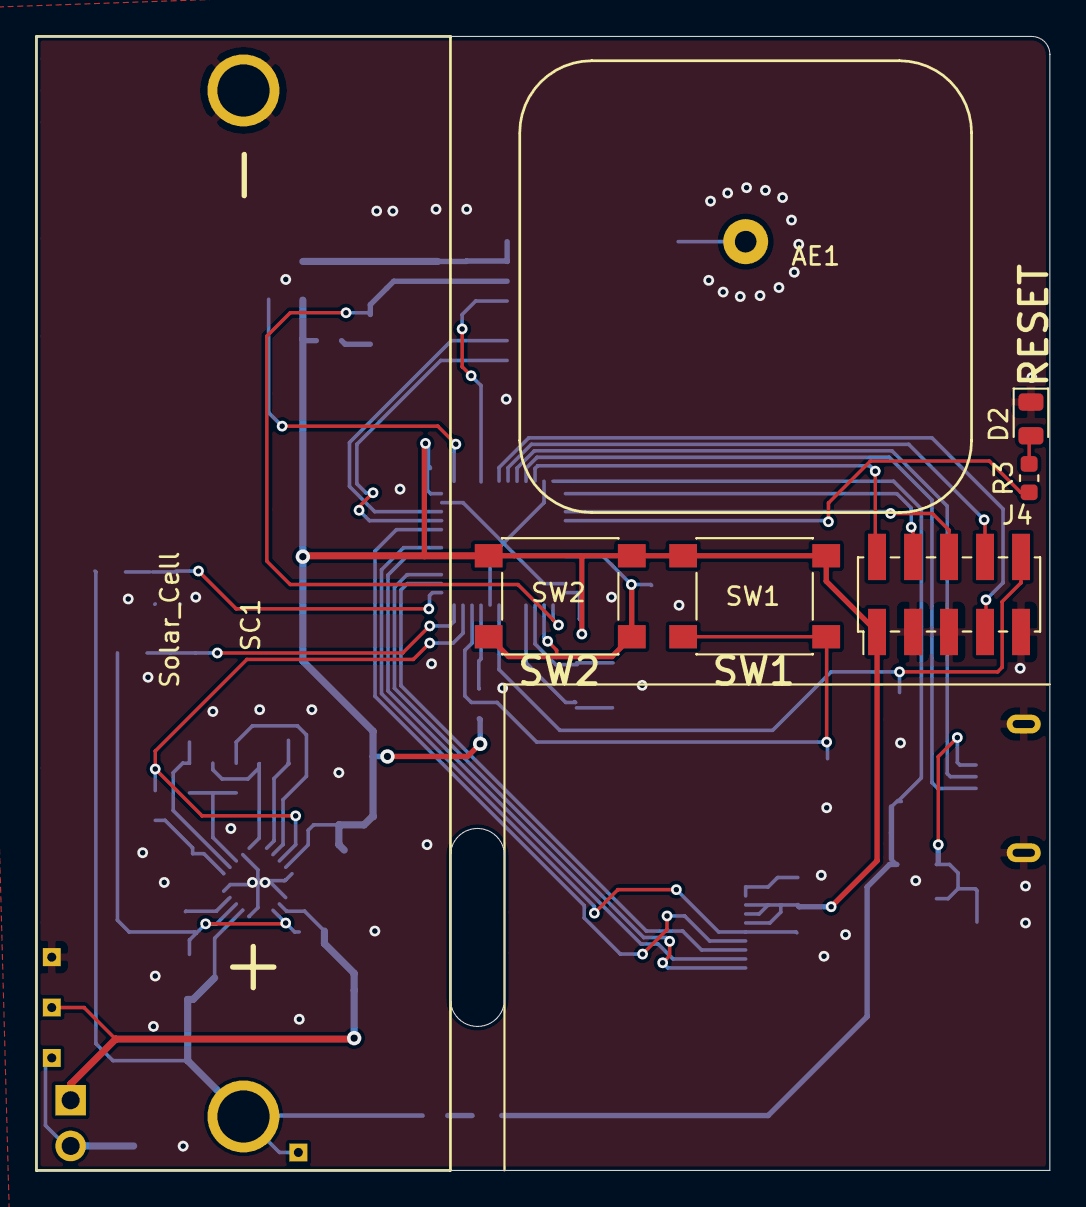
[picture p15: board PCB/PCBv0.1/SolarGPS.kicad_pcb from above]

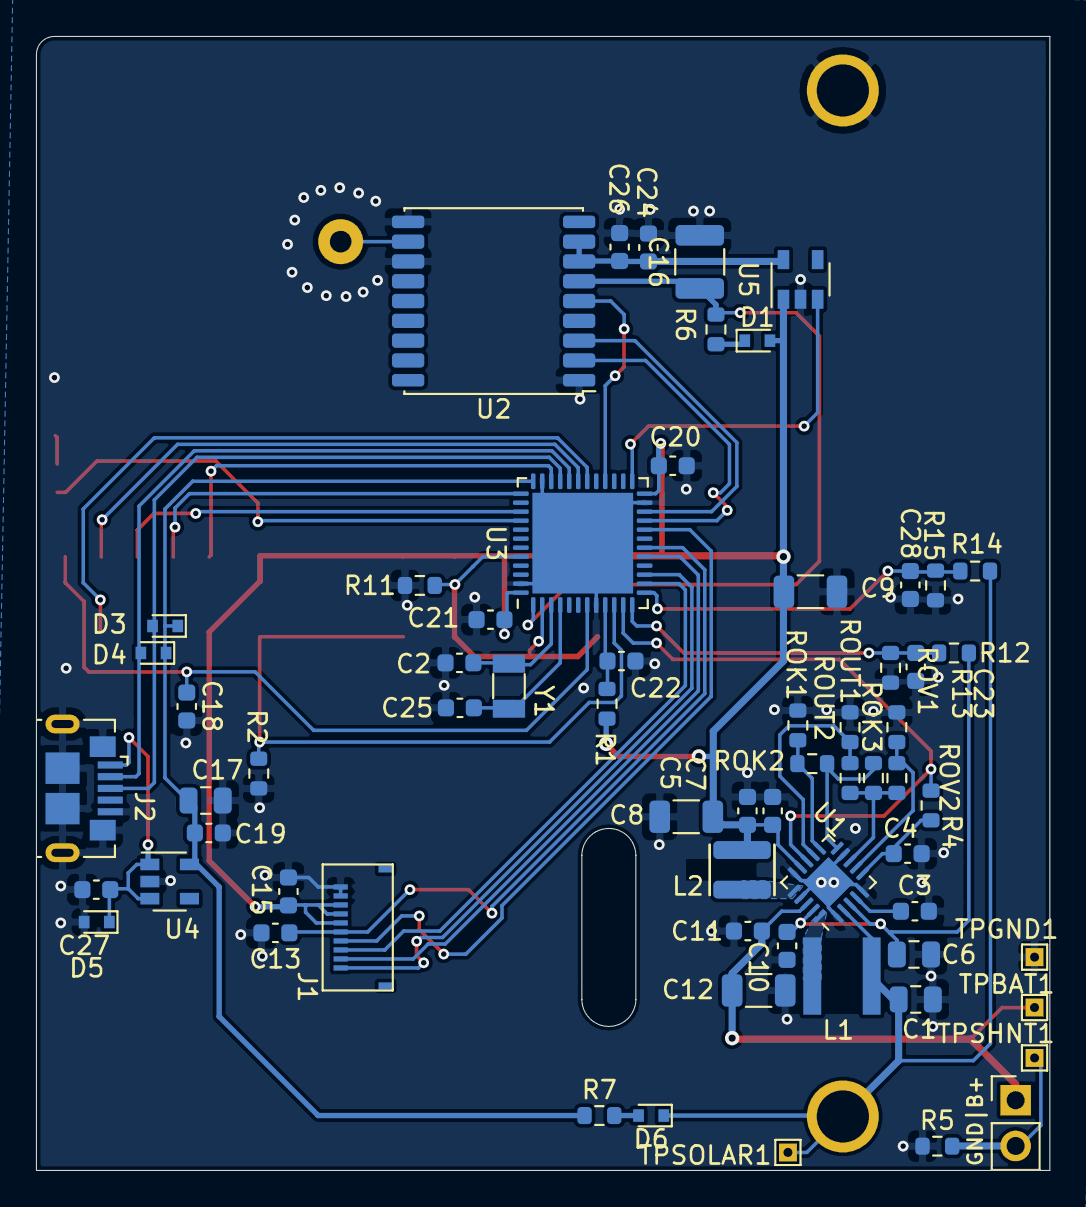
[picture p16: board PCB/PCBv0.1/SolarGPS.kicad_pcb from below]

Board: 2 copper layers, 56.3 x 63.0 mm, 72 parts (65 on the bottom side), 49 nets.

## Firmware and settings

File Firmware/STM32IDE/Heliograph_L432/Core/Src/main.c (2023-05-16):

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
/* Includes ------------------------------------------------------------------*/
#include "main.h"

/* USER CODE BEGIN Includes */
#include "myApp.h"
/* USER CODE END Includes */

ADC_HandleTypeDef hadc1;
DMA_HandleTypeDef hdma_adc1;

RTC_HandleTypeDef hrtc;

SPI_HandleTypeDef hspi1;
DMA_HandleTypeDef hdma_spi1_tx;

void SystemClock_Config(void);
static void MX_GPIO_Init(void);
static void MX_DMA_Init(void);
static void MX_SPI1_Init(void);
static void MX_ADC1_Init(void);
static void MX_LPUART1_UART_Init(void);
static void MX_RTC_Init(void);
/**
  * @brief  The application entry point.
  * @retval int
  */
int main(void)
{
  /* MCU Configuration--------------------------------------------------------*/

  /* Reset of all peripherals, Initializes the Flash interface and the Systick. */
  HAL_Init();

  /* Configure the system clock */
  SystemClock_Config();

  /* Initialize all configured peripherals */
  MX_GPIO_Init();
  MX_DMA_Init();
  MX_SPI1_Init();
  MX_ADC1_Init();
  MX_RTC_Init();
  /* USER CODE BEGIN 2 */
  myApp_init();

  /* USER CODE END 2 */

  /* Infinite loop */
  /* USER CODE BEGIN WHILE */
  while (1)
  {
	  myApp_loop();
    /* USER CODE END WHILE */

    /* USER CODE BEGIN 3 */
  }
  /* USER CODE END 3 */
}

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
/* USER CODE BEGIN 4 */
void HAL_Delay(uint32_t Delay)
{
  uint32_t tickstart = HAL_GetTick();
  uint32_t wait = Delay;

  /* Add a period to guaranty minimum wait */
  if (wait < HAL_MAX_DELAY)
  {
    wait += (uint32_t)uwTickFreq;

  }

  while ((HAL_GetTick() - tickstart) < wait)
  {
	  __WFI();
  }
}

void USER_LPUART1_UART_Init(){
	MX_LPUART1_UART_Init();
}

void USER_LPUART1_UART_DeInit(){
	LL_LPUART_DeInit(LPUART1);

	GPIO_InitTypeDef GPIO_InitStruct = {0};

	GPIO_InitStruct.Pin = GPIO_PIN_2|GPIO_PIN_3;
	GPIO_InitStruct.Mode = GPIO_MODE_ANALOG;
	GPIO_InitStruct.Pull = GPIO_NOPULL;
	HAL_GPIO_Init(GPIOA, &GPIO_InitStruct);
}


/* USER CODE END 4 */
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


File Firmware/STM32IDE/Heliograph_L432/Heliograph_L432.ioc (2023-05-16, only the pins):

Mcu.UserName=STM32L432KCUx
PA1.Signal=ADCx_IN6
PA10.GPIO_Label=DISP_EN
PA10.Signal=GPIO_Output
PA2.Signal=LPUART1_TX
PA3.Signal=LPUART1_RX
PA4.GPIO_Label=GNSS_EXT
PA4.Signal=GPIO_Output
PA5.Signal=SPI1_SCK
PA6.Signal=SPI1_MISO
PA7.Signal=SPI1_MOSI
PA8.GPIO_Label=SolarEN
PA8.Signal=GPIO_Output
PA9.GPIO_Label=DISP_CS
PA9.Signal=GPIO_Output

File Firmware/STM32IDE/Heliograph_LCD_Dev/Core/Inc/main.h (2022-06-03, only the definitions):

#define GNSS_EXT_Pin GPIO_PIN_1
#define GNSS_EXT_GPIO_Port GPIOA
#define Debug_Pin GPIO_PIN_4
#define Debug_GPIO_Port GPIOA
#define VBAT_OK_PIN_Pin GPIO_PIN_1
#define VBAT_OK_PIN_GPIO_Port GPIOB
#define VBAT_OK_PIN_EXTI_IRQn EXTI0_1_IRQn
#define DISP_EN_Pin GPIO_PIN_8
#define DISP_EN_GPIO_Port GPIOA
#define DISP_CS_Pin GPIO_PIN_10
#define DISP_CS_GPIO_Port GPIOA

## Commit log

2021-11-30 Initial Upload
    [Model1.SLDPRT, Model1.STL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]
2021-11-30 Update Test bed to 2.7Vcc
    [SolarGPS.sch, bq25505 calc.xlsx]
2021-11-30 Add details, Power Mode layout
    [Power Modes.xlsx]
2021-12-01 Update Power Modes
    [Power Modes.xlsx]
2021-12-01 Update PCB1.0 with new layout
    Reverse the LCD direction for more space on the GPS signal
    [SolarGPS.kicad_pcb, SolarGPS.sch]
2021-12-02 Cost reduction, remove second mppt
    [SolarGPS.kicad_pcb, SolarGPS.sch]
2021-12-02 Add list of cities
    [Coordinates of major cities.xlsx]
2021-12-02 Update BOM, start treebuilders
    [BOM.xlsx, Coordinates of major cities.xlsx, Coordinates.csv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]
2021-12-03 Replace Antenna
    [BOM.xlsx, SolarGPS.kicad_pcb, SolarGPS.sch]
2021-12-03 Redraw PCB1.0
    [SolarGPS.kicad_pcb, SolarGPS.sch]
2021-12-03 Update BOM
    Add 3.3pF
    [BOM.xlsx, SolarGPS.sch]
2021-12-03 Add a line
    [SolarGPS.kicad_pcb]
2021-12-06 Cost Reduction
    [BOM.xlsx, SolarGPS.kicad_pcb, SolarGPS.sch]
2021-12-06 Most Cost Savings
    [BOM.xlsx, SolarGPS.kicad_pcb, SolarGPS.sch]
2021-12-08 Mess with 3D
    [Model1.SLDPRT, Model1.STL, PCB1.0.SLDPRT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]
2021-12-10 Rebuild outputs for production sample
    [SolarGPS-B_Cu.gbr, SolarGPS-B_Mask.gbr, SolarGPS-B_Paste.gbr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]
2021-12-13 Revert "Merge branch 'main' of https://github.com/jacky4566/Veridian-Heliograph"
    This reverts commit 3d311697883c021d2cdad3487d82eaf0104020f1, reversing
    changes made to 2ae0f60846ad75c4f8cb230a5fde49ffea6f6208.
    [Model1.SLDPRT, Model1.STL, PCB1.0.SLDPRT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]
2021-12-13 Firmware resolve
    [Coordinates of major cities.xlsx, Coordinates.csv, Power Modes.xlsx]
2021-12-22 Start GNSS Driver
2021-12-23 Tweak part numbers
    [SolarGPS.kicad_pcb, SolarGPS.sch]
2021-12-25 Add PCB1.1
    [BOM.xlsx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]
2021-12-28 Add some GNSS ground work and IWDG 2s
2021-12-29 Add some experimental low power stuff for LPUART
2021-12-29 Add some SPI framework
2021-12-29 split out ADC SPI functions
2022-01-10 Add some rotate display stuff
    [SolarGPS.kicad_sch]
2022-01-13 Change VCC to 2.87 Remove LCD connector
    [SolarGPS.kicad_pcb, SolarGPS.sch]
2022-01-13 Cost savings!
    [SolarGPS.kicad_pcb, SolarGPS.sch, worldcities.csv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]
2022-01-20 tweak PCB1.1 add some notes
    [SolarGPS.sch]
2022-01-20 Play with USB idea. Update to KiCad 5
    [SolarGPS.kicad_pcb, SolarGPS.sch]
2022-01-25 Add more App, DropBLE
    [SolarGPS-B_Cu.gbr, SolarGPS-B_Mask.gbr, SolarGPS-B_Paste.gbr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]
2022-01-25 Change solder mask
    [SolarGPS-B_Cu.gbr, SolarGPS-B_Mask.gbr, SolarGPS-B_Paste.gbr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]
2022-01-25 Add some datasheets
    [SolarGPS.kicad_sch]
2022-01-26 Remove control app
    [BOM.xlsx, Power Levels.xlsx, SolarGPS.kicad_pcb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]
2022-02-01 Add custom library revise M4 mount
    [SolarGPS.kicad_pcb, SolarGPS.kicad_sch]
2022-02-01 Update PCB 1.1
    [SolarGPS.kicad_pcb, SolarGPS.kicad_sch]
2022-02-01 Tweak PCB
    [SolarGPS.kicad_pcb, SolarGPS.kicad_sch]
2022-02-02 Add V1.2 with UART fixes
    [BOM.xlsx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]
2022-02-02 Tweak Grounding
    [SolarGPS.kicad_pcb]
2022-02-07 Rebuild PCB1.2 and submit for build
    [SolarGPS-B_Cu.gbr, SolarGPS-B_Mask.gbr, SolarGPS-B_Paste.gbr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]
2022-03-03 Move symbols to lib
    [SolarGPS.kicad_pcb, SolarGPS.kicad_sch]
2022-03-03 Drop MPPT buck for diode cost
    [SolarGPS.kicad_pcb, SolarGPS.kicad_sch]
2022-03-08 Change LCD
    [BOM.xlsx, SolarGPS.kicad_pcb, SolarGPS.kicad_sch]
2022-04-09 Rework power system for hybrid cap and bq25770
    [SolarGPS.kicad_pcb, SolarGPS.kicad_sch, bq25505 calc.xlsx]
2022-04-09 Tweak Epaper driver
    [SolarGPS-B_Cu.gbr, SolarGPS-B_Mask.gbr, SolarGPS-B_Paste.gbr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]
2022-04-10 Fix Reverse Epaper Connector
    [SolarGPS-B_Cu.gbr, SolarGPS-B_Mask.gbr, SolarGPS-B_Paste.gbr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]
2022-04-18 Update 1.4 BOM
    [BOM.xlsx, SolarGPS.kicad_pcb, SolarGPS.kicad_sch]
2022-04-19 firmware stuff
    [BOM.xlsx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]
2022-04-19 1.4 MEga328PB
    [BOM.xlsx, SolarGPS.csv, SolarGPS.kicad_pcb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]
2022-04-20 add tqfp footprint
    [SolarGPS.kicad_pcb, SolarGPS.kicad_sch]
2022-04-20 reduce power BOM
    [SolarGPS.kicad_pcb, SolarGPS.kicad_sch]
2022-04-28 Version 1.4
    [SolarGPS-B_Cu.gbr, SolarGPS-B_Mask.gbr, SolarGPS-B_Paste.gbr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]
2022-05-11 tweak pcb1.5
    [SolarGPS.kicad_pcb, SolarGPS.kicad_sch]
2022-05-11 Update PCB 1.5
2022-05-12 Add demo code
    [SolarGPS.kicad_pcb]
2022-05-14 Some dumb changes
    [SolarGPS.kicad_pcb, SolarGPS.kicad_sch, bq25505 calc.xlsx]
2022-05-16 Manufacture 1.5 PCB
    [SolarGPS-B_Cu.gbr, SolarGPS-B_Mask.gbr, SolarGPS-B_Paste.gbr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]
2022-05-30 Start PCB1.6
    [Power Levels.xlsx, SolarGPS.kicad_pcb, SolarGPS.kicad_sch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]
2022-06-01 More Progress
    [SolarGPS.kicad_pcb, SolarGPS.kicad_sch]
2022-06-04 Replace GNSS with L96
    [SolarGPS.kicad_pcb, SolarGPS.kicad_sch]
2022-08-06 Update PCBV10
    [SolarGPS.kicad_pcb, SolarGPS.kicad_sch]
2022-11-03 Tweak 1.7
    [SolarGPS.kicad_pcb, SolarGPS.kicad_sch]
2022-11-03 Submit board 1.7
    [SolarGPS-B_Cu.gbr, SolarGPS-B_Mask.gbr, SolarGPS-B_Paste.gbr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]
2022-11-23 Tweak UI and Voltages
2023-04-15 add USB!
    [SolarGPS.kicad_pcb, SolarGPS.kicad_sch]
2023-04-17 Add USB pulldown and SWO
    [SolarGPS.kicad_pcb, SolarGPS.kicad_sch]
2023-04-20 Do PCB 1.7
    [SolarGPS-B_Cu.gbr, SolarGPS-B_Mask.gbr, SolarGPS-B_Paste.gbr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]
2023-04-26 Tweak Resistors
    [SolarGPS.kicad_sch]
2023-05-16 Add Power Save GNSS

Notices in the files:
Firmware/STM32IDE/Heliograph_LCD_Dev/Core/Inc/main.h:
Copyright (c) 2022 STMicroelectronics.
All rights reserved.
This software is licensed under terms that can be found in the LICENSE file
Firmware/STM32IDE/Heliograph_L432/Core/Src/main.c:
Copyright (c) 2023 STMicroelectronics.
